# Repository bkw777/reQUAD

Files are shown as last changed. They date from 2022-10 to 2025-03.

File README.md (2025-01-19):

# reQUAD

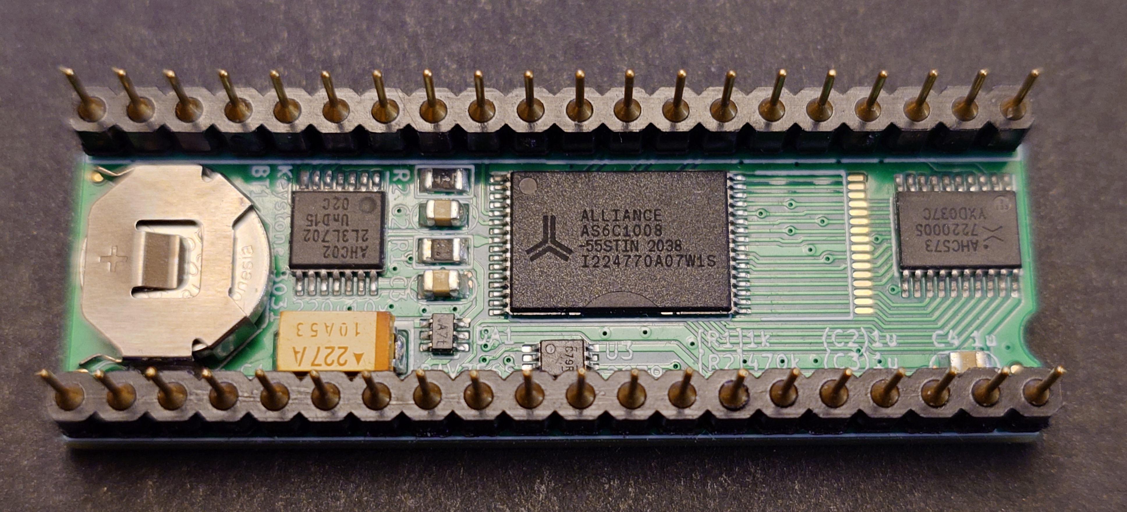
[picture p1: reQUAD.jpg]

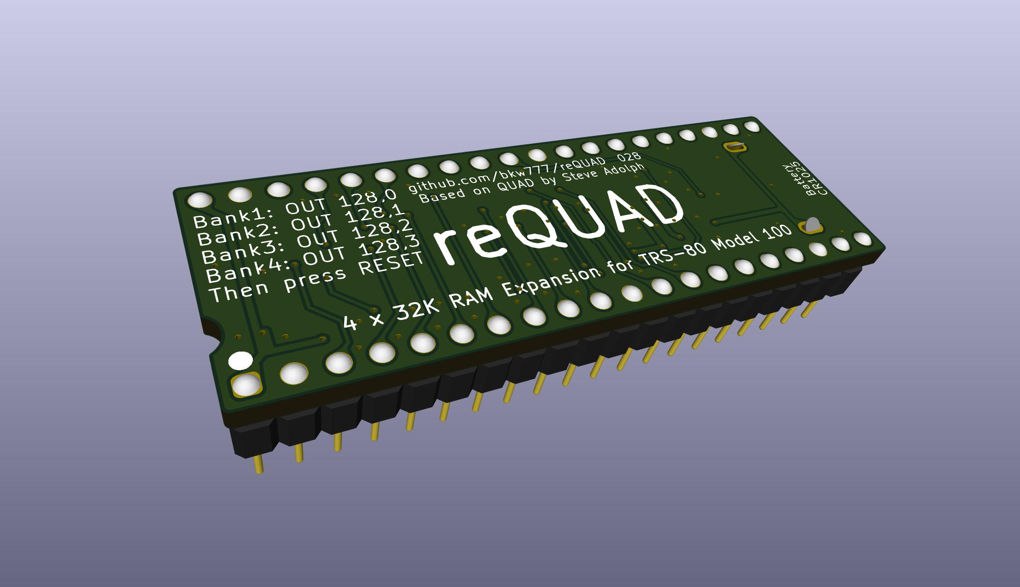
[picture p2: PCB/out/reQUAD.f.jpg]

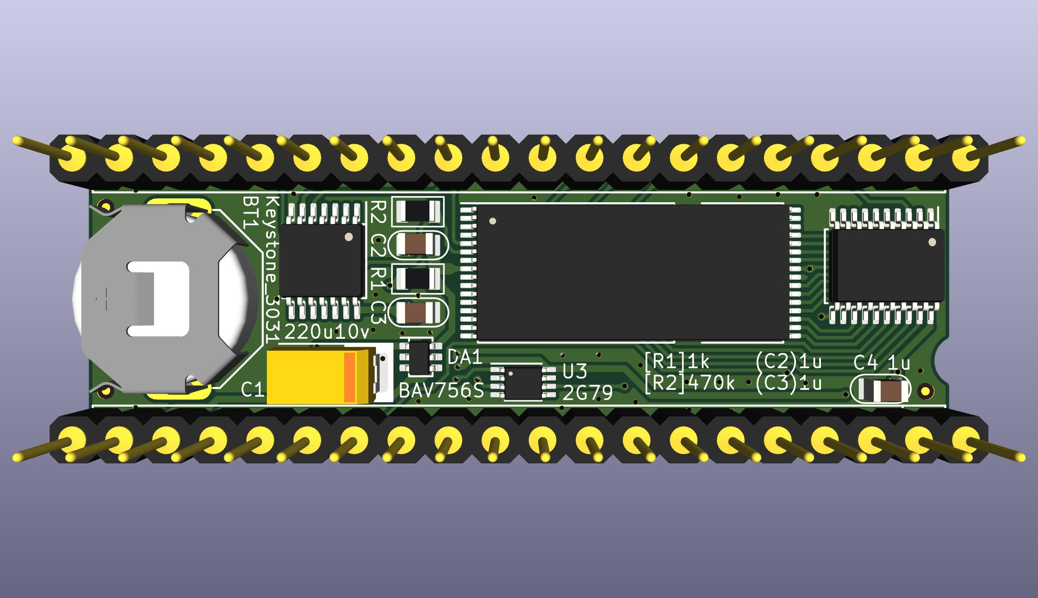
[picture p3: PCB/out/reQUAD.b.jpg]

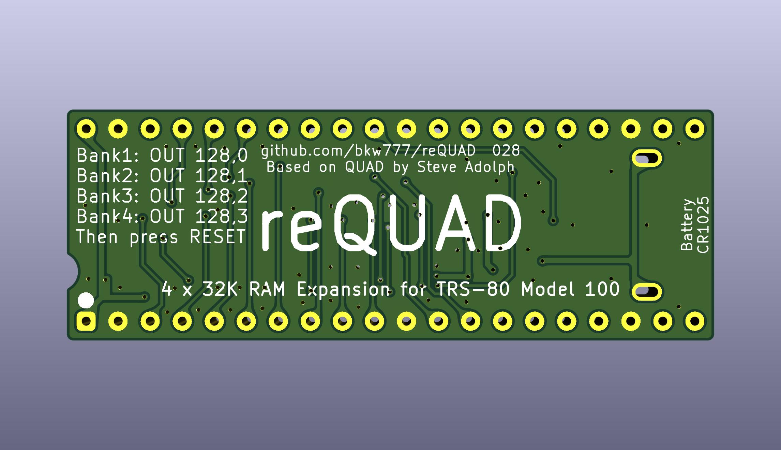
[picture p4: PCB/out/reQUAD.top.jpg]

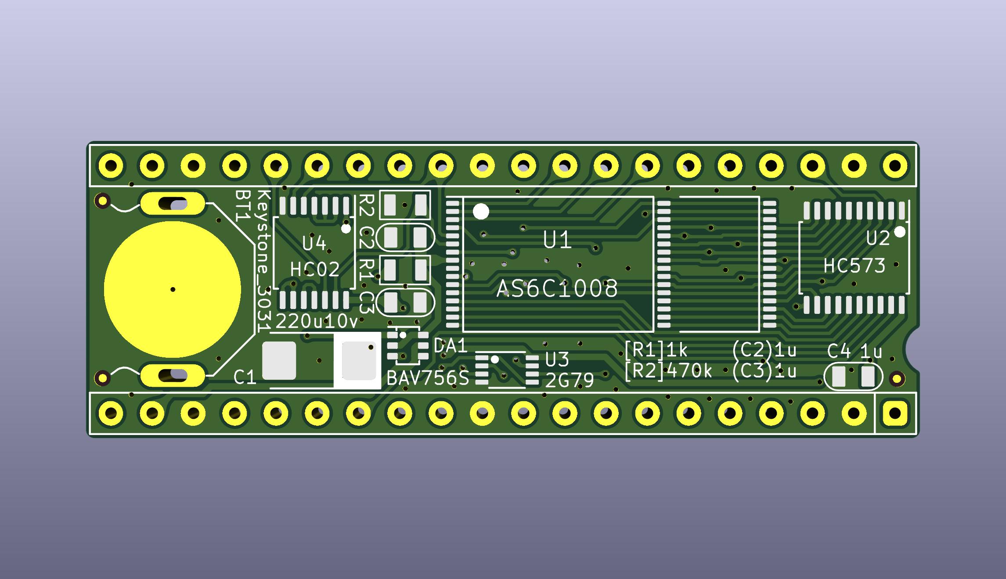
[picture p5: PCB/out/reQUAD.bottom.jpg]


reQUAD.bom.csv

## About
This is a derivative of [QUAD](http://bitchin100.com/wiki/index.php?title=QUAD) by Steve Adolph.

## Differences from the original
Removed the resistor-cap power-on-reset circuit and resettable flip-flop for a simple flip-flop.  
Added battery and battery-change cap.  
Added pulldown on the sram CE2.

## To Build it
PCB [PCBWAY](https://www.pcbway.com/project/shareproject/reQUAD_RAM_Expansion_for_TRS_80_Model_100_8690cd19.html)  
BOM [DigiKey](https://www.digikey.com/short/z47bn0mw)

Build notes,  
The pin 1 mark on DA1, BAV756S, is tiny and faint, but there is one, you just need a lot of magnification and light. The markings look like `.A7t` and the . is at pin 1. The pinout is not symmetric, and so the part must be installed in the correct orientation.

## To Use it

The device disables and replaces the machine's original internal 32k RAM, so copy any files off of the computer before installing the reQUAD. You won't be able to access the internal ram except by removing the reQUAD.

The first time the device is powered up, it will be in a random bank number.

The first thing you should do after install is "blindly" switch to each bank,  
and do a cold-reset in each bank to wipe all banks of any random data.  
(only cold-reset, not power-cycle. If you power-cycle, the reQUAD may switch to a random bank again.)

In BASIC type `OUT 128,3` \[Enter\], then CTRL+BREAK+RESET.  
In BASIC type `OUT 128,2` \[Enter\], then CTRL+BREAK+RESET.  
In BASIC type `OUT 128,1` \[Enter\], then CTRL+BREAK+RESET.  
In BASIC type `OUT 128,0` \[Enter\], then CTRL+BREAK+RESET.  

Now all 4 banks have been wiped clean of any random data, and you are sitting in bank 1.  
From now on, don't do CTRL+BREAK+RESET any more, just RESET (unless you actually want to wipe a bank).  

Now there are 3 main options for using the banks from no on.  
Manual control,  
BANK.BA,  
0QUAD

### Manual Control

To switch banks manually without 0QUAD or BANK.BA:  
In BASIC, type `OUT 128,n`, where n is the desired bank number from 0 to 3,  
then immediately press RESET on the back of the machine.

`OUT 128,0` switches to bank 1  
`OUT 128,1` switches to bank 2  
`OUT 128,2` switches to bank 3  
`OUT 128,3` switches to bank 4  

The cpu has no knowledge that it's entire ram universe has been replaced and all it's current register contents and pointers and such are invalid, so the main rom must be restarted IMMEDIATELY after the OUT command.

So after the OUT command, ignore the screen and press the RESET button on the back of the machine.

Pressing RESET is only needed when switching manually this way instead of using BANK.BA or 0QUAD.  
BANK.BA and 0QUAD both induce a reset themselves.

### BANK.BA
The next-simplest option for controlling the reQUAD is to copy this 4-line BASIC program into each bank,  
and save it with a name matching the current bank it's in.

First, ensure you are in bank 1:  
In BASIC, type `OUT128,0` \[Enter\], then press RESET.

Then in BASIC type-in this program:
```
1 INPUT"Bank(1-4)";X:IFX<1ORX>4THEN 1
2 A#=0:B=VARPTR(A#):POKEB,249
3 POKEB+1,195:POKEB+2,241:POKEB+3,118
4 CALLB,X-1,30481
```

Then `SAVE "BANK1"`

Now you know you are in bank1 because it says BANK1.BA in the main menu,  
and you can BANK1.BA to switch to any other bank.

Repeat for all 4 banks  
run BANK1.BA, answer "2", you are now in a new empty bank2, type-in the program again, `SAVE "BANK2"`  
run BANK2.BA, answer "3", type-in, `SAVE "BANK3"`  
run BANK3.BA, answer "4", type-in, `SAVE "BANK4"`  

### 0QUAD

Install [0QUAD](APP/)

Refer to the docs for the original [QUAD](http://bitchin100.com/wiki/index.php?title=QUAD)

### Example Installing 0QUAD using dl2 and teeny
(this will wipe all data)

QUAD.BA must be copied as a binary via TPDD, it can't be copied in ascii format using ordinary text transfer with TELCOM.  

This example will use dl2 on the pc to bootstrap install TEENY on the 100, and then use TEENY and dl2 to copy QUAD.BA to the 100.
You can use any other TPDD emulator instead of dl2, like LaddieAlpha or a Backpack, and you can use any TPDD client instead of TEENY, like TS-DOS or DSKMGR.

On the pc, install [dl2](https://github.com/bkw777/dl2/)

On the 100, in BASIC: `OUT 128,0`  
Then do a cold reset: CTRL+BREAK+RESET

On the pc:
```
$ cd APP
$ dl -v -b TEENY.100 && dl -v -u
```

On the 100, in BASIC: `RUN "COM:98N1ENN"`  
Press ENTER at the end of the TEENY install to accept the default install location.  
`CLEAR 0,62213`  
Press F8 to exit to the main menu and run TEENY.CO  
Use TEENY to copy QUAD.BA from the pc  
```
> L QUAD  .BA
> Q
```

On the pc: Ctrl+C to exit dl2

On the 100: Run QUAD.BA  
Answer "1" to the "Which bank are you in?" question.  

0QUAD is now installed in bank 1, but is invisible.

Type `0QUAD` \[Enter\] at the main menu (not in BASIC) to run 0QUAD

Now the top-right corner will show "#1" to show that you are currently in bank 1.  
Press F1 to pull up the bank-switch menu, then press F2 to switch to bank 2.

You are now in bank 2 which is a new empty bank.  
0QUAD is not installed in this bank yet.

Install 0QUAD in bank 2 by repeating everything after the OUT command above, including the cold reset.  
Answer "2" at the "Which bank?" question.  
Repeat again for banks 3 and 4.

Once 0QUAD is installed in all banks, you can use it to switch from any bank to any other bank, and you don't need to press the RESET button after each switch when using 0QUAD to switch.

## Thanks
Thanks to Steve Adolph for sharing his original design and allowing this derivative.

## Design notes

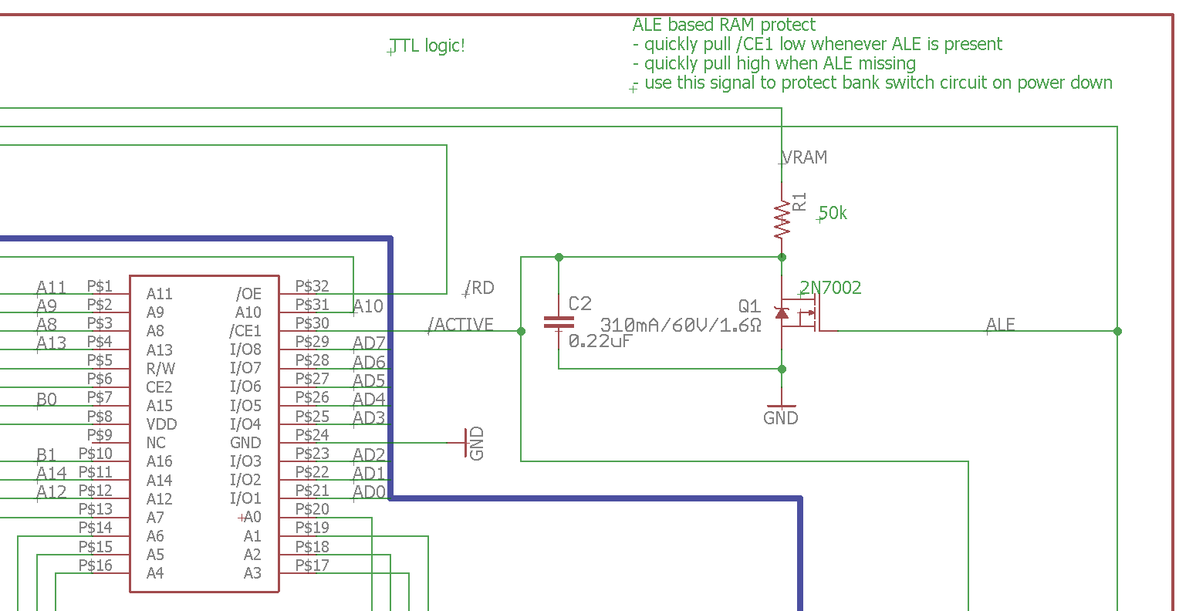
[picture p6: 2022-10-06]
ref/ram_protect_idea.png

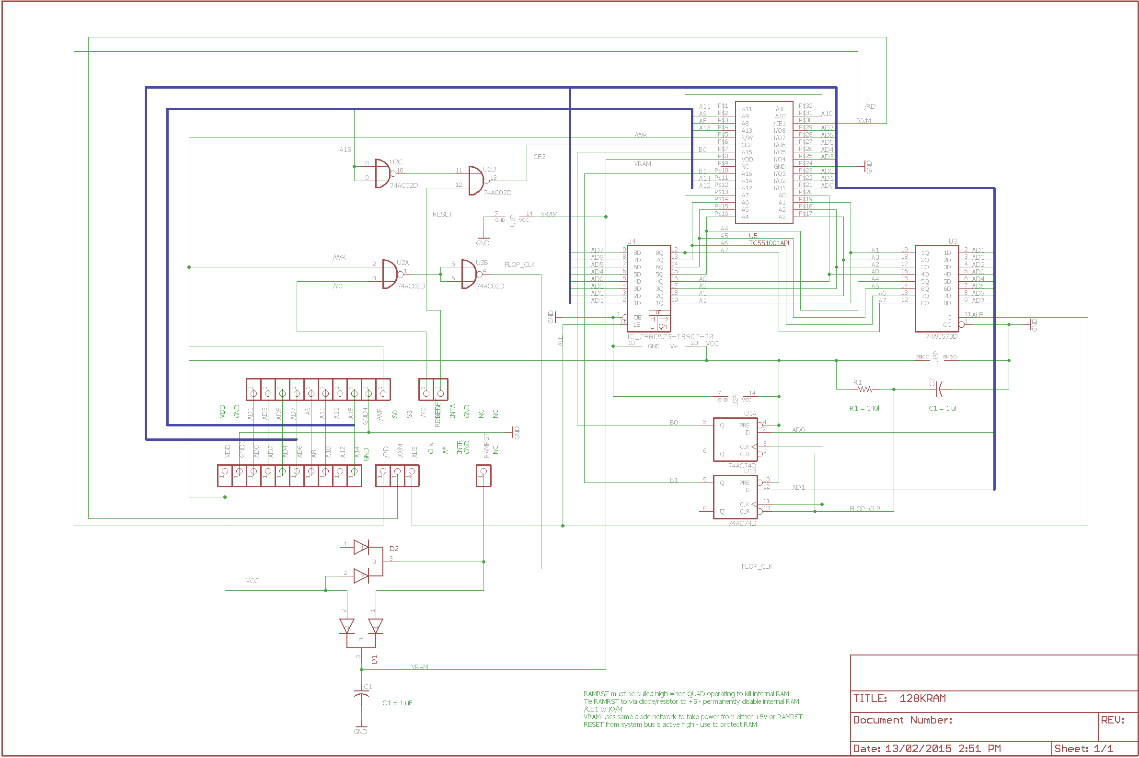
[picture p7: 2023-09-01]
ref/QUAD_v4_schemactic.png

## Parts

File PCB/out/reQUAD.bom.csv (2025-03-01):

Reference | Value | Datasheet | Footprint | Qty | DNP | MPN | Description
BT1 | Keystone_3031 | datasheet/Keystone_3031.pdf | 000_LOCAL:Keystone_3031 | 1 |  | Keystone 3031 | Battery Retainer Coin, 10.0mm 1 Cell PC Pin
C1 | 220u10v | datasheets/TAJ.odf | 000_LOCAL:CP_6032 | 1 |  | TAJC227K010RNJ | CAP TANT 220UF 10% 10V 2312
C2,C3,C4 | 1u | datasheets/CL21B105KAFNNNE.pdf | 000_LOCAL:C_0805 | 3 |  | CL21B105KAFNNNE | CAP CER 1UF 25V X7R 0805
DA1 | BAV756S | datasheets/BAV756S.pdf | 000_LOCAL:SOT-363 | 1 |  | BAV756S,115 | DIODE ARRAY GP 90V 250MA 6TSSOP
J1 | Model_100_System_BUS | datasheets/TRS-80_Model_100_User_Guide.pdf | 000_LOCAL:DIP-40_PCB | 1 |  | 920-0172-01 | CONN HEADER VERT 40P 2.54MM
R1 | 1k | datasheets/RK73.pdf | 000_LOCAL:R_0805 | 1 |  | RK73B2ATTD102J | RES 1K OHM 5% 1/4W 0805
R2 | 470k | datasheets/PYu-RC_Group_51_RoHS_L_12.pdf | 000_LOCAL:R_0805 | 1 |  | RC0805FR-07470KL | RES 470K OHM 1% 1/8W 0805
U1 | AS6C1008 | datasheets/AS6C1008.pdf | 000_LOCAL:TSOP32-dual | 1 |  | AS6C1008-55STIN | IC SRAM 1Mx8 PARALLEL 5V 32STSOP
U2 | HC573 | datasheets/HC573.pdf | 000_LOCAL:TSSOP-20_4.4x6.5mm_P0.65mm | 1 |  | 74HC573PW,118 | IC D-TYPE TRANSP SGL 8:8 20TSSOP
U3 | 2G79 | datasheets/2G79.pdf | 000_LOCAL:VSSOP-8_2.3x2mm_P0.5mm | 1 |  | SN74LVC2G79DCUR | Flip Flop 2 Element D-Type 1 Bit Positive Edge 8-VFSOP (0.091", 2.30mm Width)
U4 | HC02 | datasheets/HC02.pdf | 000_LOCAL:TSSOP-14_4.4x5mm_P0.65mm | 1 |  | 74HC02PW,118 | IC GATE NOR 4CH 2-INP 14TSSOP

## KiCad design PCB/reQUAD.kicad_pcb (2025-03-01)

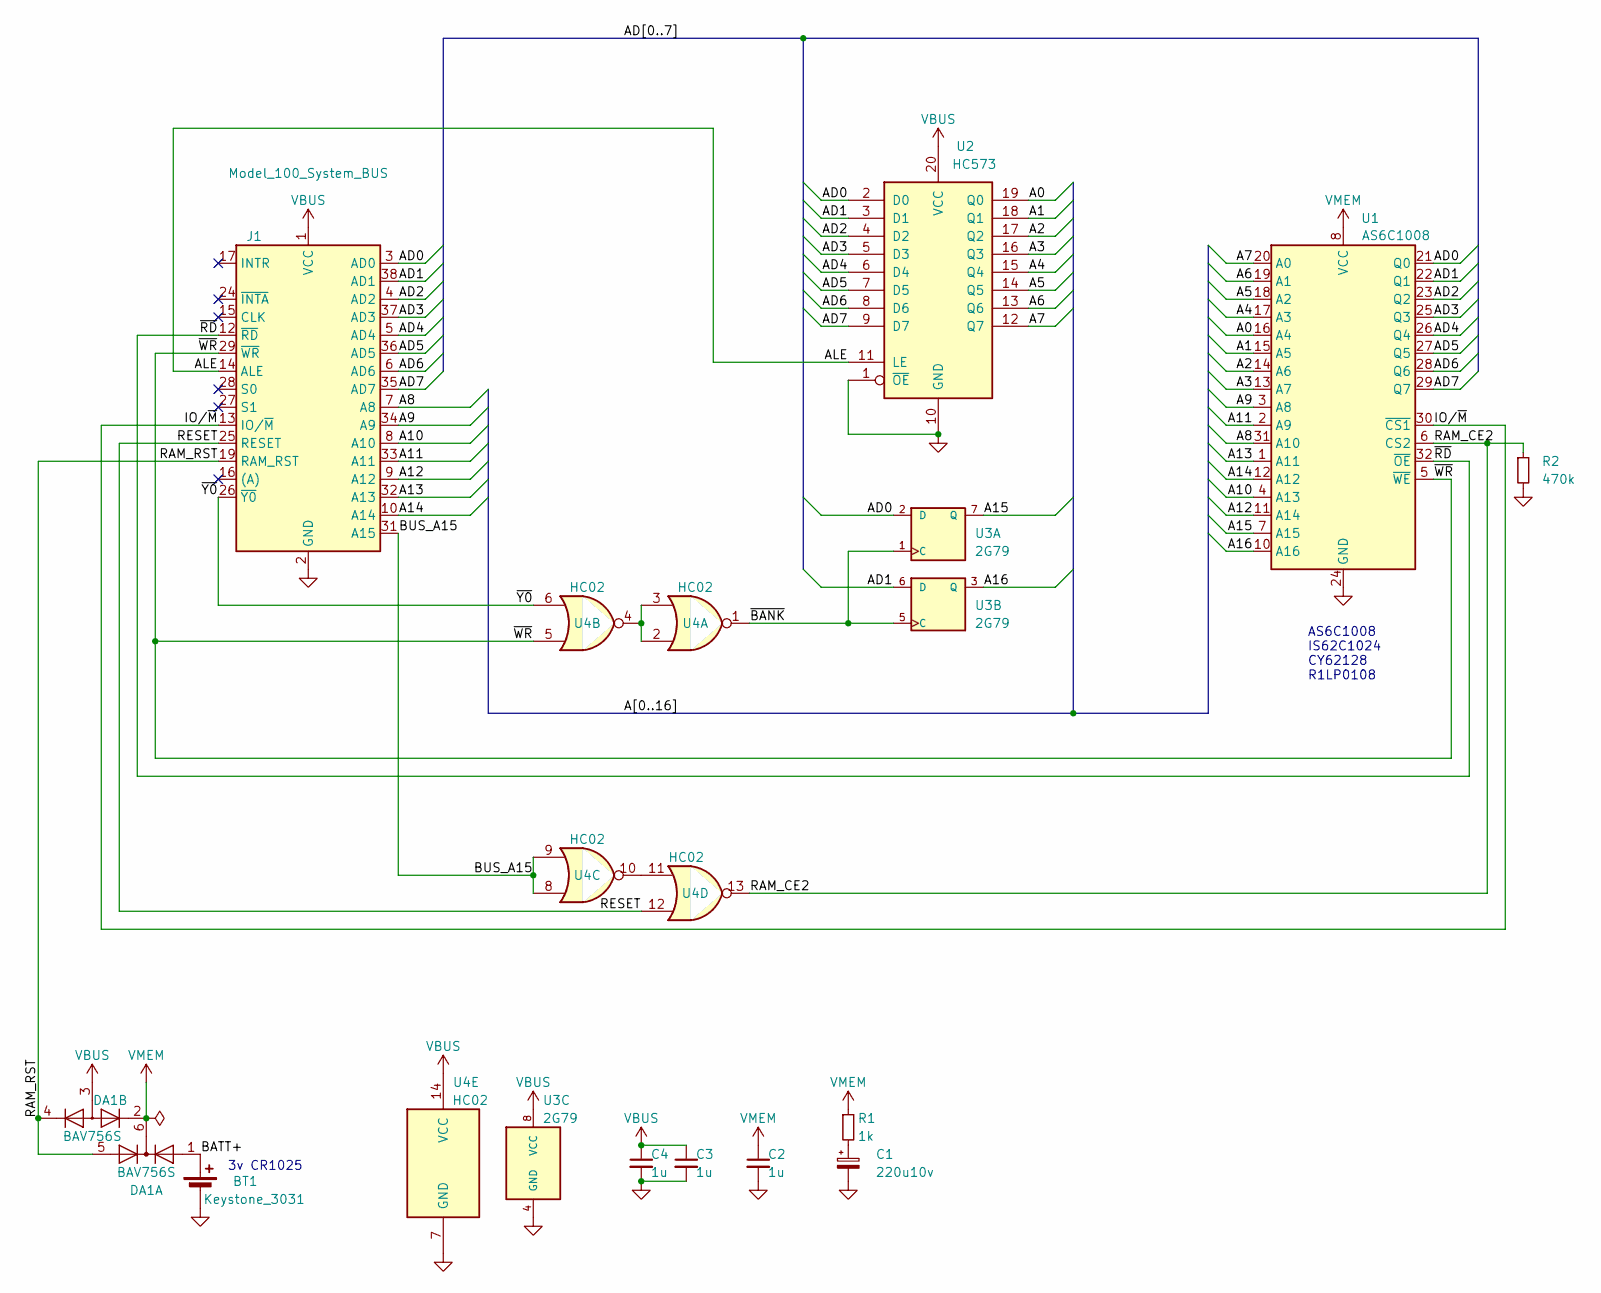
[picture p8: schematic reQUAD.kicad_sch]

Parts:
BT1: Keystone_3031; MPN Keystone 3031
C1: 220u10v; CP_6032; MPN TAJC227K010RNJ
C2, C3, C4: 1u; C_0805; MPN CL21B105KAFNNNE
DA1: BAV756S; SOT-363; MPN BAV756S,115
J1: Model_100_System_BUS; DIP-40_PCB; MPN 920-0172-01
R1: 1k; R_0805; MPN RK73B2ATTD102J
R2: 470k; R_0805; MPN RC0805FR-07470KL
U1: AS6C1008; TSOP32-dual; MPN AS6C1008-55STIN
U2: HC573; TSSOP-20_4.4x6.5mm_P0.65mm; MPN 74HC573PW,118
U3: 2G79; VSSOP-8_2.3x2mm_P0.5mm; MPN SN74LVC2G79DCUR
U4: HC02; TSSOP-14_4.4x5mm_P0.65mm; MPN 74HC02PW,118

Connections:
/A0: U1.16 (A4), U2.19 (Q0)
/A1: U1.15 (A5), U2.18 (Q1)
/A2: U1.14 (A6), U2.17 (Q2)
/A3: U1.13 (A7), U2.16 (Q3)
/A4: U1.17 (A3), U2.15 (Q4)
/A5: U1.18 (A2), U2.14 (Q5)
/A6: U1.19 (A1), U2.13 (Q6)
/A7: U1.20 (A0), U2.12 (Q7)
/A8: J1.7 (A8), U1.31 (A10)
/A9: J1.34 (A9), U1.3 (A8)
/A10: J1.8 (A10), U1.4 (A13)
/A11: J1.33 (A11), U1.2 (A9)
/A12: J1.9 (A12), U1.11 (A14)
/A13: J1.32 (A13), U1.1 (A11)
/A14: J1.10 (A14), U1.12 (A12)
/A15: U1.7 (A15), U3.7 (Q)
/A16: U1.10 (A16), U3.3 (Q)
/AD0: J1.3 (AD0), U1.21 (Q0), U2.2 (D0), U3.2 (D)
/AD1: J1.38 (AD1), U1.22 (Q1), U2.3 (D1), U3.6 (D)
/AD2: J1.4 (AD2), U1.23 (Q2), U2.4 (D2)
/AD3: J1.37 (AD3), U1.25 (Q3), U2.5 (D3)
/AD4: J1.5 (AD4), U1.26 (Q4), U2.6 (D4)
/AD5: J1.36 (AD5), U1.27 (Q5), U2.7 (D5)
/AD6: J1.6 (AD6), U1.28 (Q6), U2.8 (D6)
/AD7: J1.35 (AD7), U1.29 (Q7), U2.9 (D7)
/ALE: J1.14 (ALE), U2.11 (LE)
/BATT+: BT1.1 (+), DA1.1 (A1)
/BUS_A15: J1.31 (A15), U4.8, U4.9
/IO/~M: J1.13 (IO/~M), U1.30 (~CS1)
/RAM_CE2: R2.1, U1.6 (CS2), U4.13
/RAM_RST: DA1.4 (K3), DA1.5 (A4), J1.19 (RAM_RST)
/RESET: J1.25 (RESET), U4.12
/~BANK: U3.1 (C), U3.5 (C), U4.1
/~RD: J1.12 (~RD), U1.32 (~OE)
/~WR: J1.29 (~WR), U1.5 (~WE), U4.5
/~Y0: J1.26 (~Y0), U4.6
GND: BT1.2 (-), C1.2, C2.2, C3.2, C4.2, J1.2 (GND), J1.11 (GND), J1.18 (GND), J1.23 (GND), J1.30 (GND), J1.39 (GND), R2.2, U1.24 (GND), U2.1 (~OE), U2.10 (GND), U3.4 (GND), U4.7 (GND)
unnamed: C1.1, R1.2
unnamed: U4.2, U4.3, U4.4
unnamed: U4.10, U4.11
VBUS: C3.1, C4.1, DA1.3 (CA), J1.1 (VCC), J1.40 (VCC), U2.20 (VCC), U3.8 (VCC), U4.14 (VCC)
VMEM: C2.1, DA1.2 (K2), DA1.6 (CK), R1.1, U1.8 (VCC)

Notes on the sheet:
3v CR1025
AS6C1008 IS62C1024 CY62128 R1LP0108

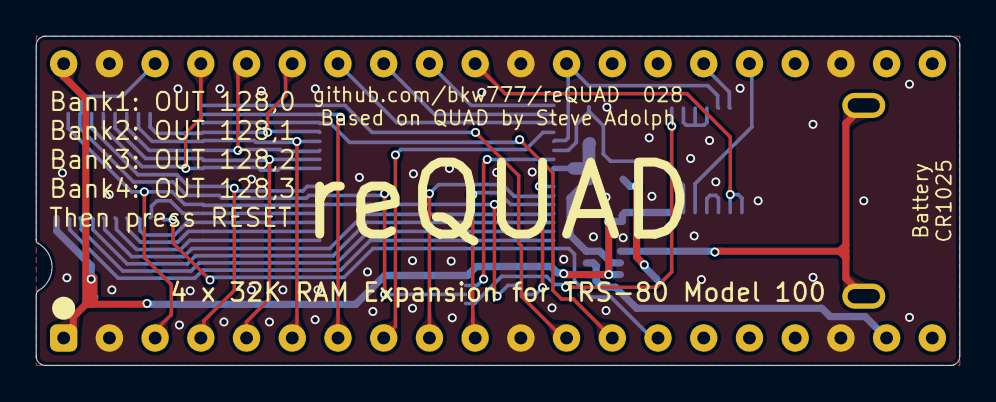
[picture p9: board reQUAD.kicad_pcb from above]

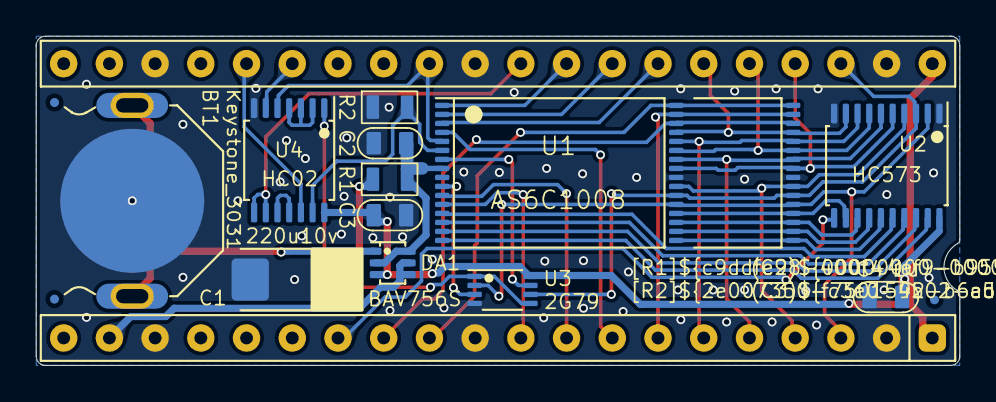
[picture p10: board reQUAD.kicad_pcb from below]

Board: 2 copper layers, 51.3 x 18.3 mm, 16 parts (16 on the bottom side), 42 nets.

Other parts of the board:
F1, F2, F3: Fiducial_0.5_1.0

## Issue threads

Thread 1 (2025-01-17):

v028 Board, Blank Screen after OUT 128,0; Enter; Reset Button

techfixpros, 2025-01-17:
Model 100
FlexROM 102 w/Y2K patched 102 ROM
24k Stock
Recapped and RAM Batt replaced

Built v028 reQUAD, and on initial boot, the total RAM shows 29k, so it was detected and overrode the on-board ram.
Ran OUT 128,0, then enter, then reset button. Screen is now blank, and typing continuously does not make the unit beep.
CTRL+Brk+Reset does not recover unit. Unit will work properly with reQUAD removed.
Removed battery from reQUAD, reinserted and screen is still blank.
Reinserted battery and reQUAD and screen is still blank.

bkw777, 2025-01-18:
As it happens I just built one a week or so ago.

some suggestions:

* cold-reset first thing in any new bank
After switching to any new bank for the first time on a new unit that was just built, or on a unit that has lost all power (both remove the battery and short the big yellow cap), the contents may possibly be random, not valid data and not all clean 00 or FF. So one time per bank, the first time after switching to a new bank that has never been used yet, it's not a bad idea to do a cold-reset: ctrl+break+reset. This wipes all ram in that bank, ensuring it's in a sane state to go from there.

* double-check for shorts on the sram. Soldering the TSOP is tricky and it's easy to have bridges that aren't always obvious visually, like the bridge is behind the pins. So a lot of light and magnification to look real good at the pins.

* double-check for not-really-connected pins on the sram. it's also easy for a pin to look soldered but actually just be resting on top of the pad.

* lake of flux while soldering

You might try just using wick and flux to first soak up the existing solder and re-do the soldering with a lot of flux and more attention to bridges and false not-really-connected, without fully removing the parts.

Really the same applies to all the pins obviously but the TSOP are the smallest and easiest to get an error.

If it really all looks good, get some chipquick or fastchip desoldering alloy and desolder everything and just redo it. You just melt a ball of it on the iron and then run the ball along both rows of pins and after a few swipes back & forth the chip comes loose. Then use wick to clean up the loose chip and it's ready to go on a new board.

* verify the orientation of all ic's
The bav756s is particularly annoying. You have to use a lot of light and magnification to make out the markings ".A7t" and the "." is pin 1.

Here are pics of a working unit for reference of the way the ics should look.

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

After all that, the bad news is, it is actually possible to have a bad ic. I just rescently got a dud 4MB $35 sram for REXCPM. The only way I know the ic was bad and not any of the tricky soldering, is I just have more than one of all parts and I actually desoldered everything and reassembled on a new board, got the same result, replaced just the sram on that same board and it worked. As far as I can remember, that is the only bad ic I got new from digikey or mouser, but it shows that it does happen. Or possibly I killed it in handling. I work on an antistatic mat but I'm not very careful really.

Yours half-working makes me more suspect the 2G79 or possibly any of the other ics since they all play a part in the bank switch, or just general soldering.

The most likely thing is simply the soldering. I've had units not work several times and except for that one bad sram it's always been the soldering, and just redoing it made it work.

bkw777, 2025-01-18:
Wait, how do you have a flexrom 102 in a 100?
Do you actually have one of the late model 100's that doesn't have the non-standard pinout for the main rom?
I've heard of those but never seen one. I figured they were either a myth or very rare.

bkw777, 2025-01-18:
I suppose I could have tested that sram in a tl866 eprom reader. I have the right adapter. Oh well gone now.

techfixpros, 2025-01-18:
> Wait, how do you have a flexrom 102 in a 100? Do you actually have one of the late model 100's that doesn't have the non-standard pinout for the main rom? I've heard of those but never seen one. I figured they were either a myth or very rare.

My original system ROM is a [3256c07-3h1](https://imgur.com/gallery/trs-80-model-100-3256c07-3h1-system-rom-ORf6xtk) <- Is the picture of it.

I will just re-order the parts to populate another reQUAD board (have two more bare). The IC orientation is correct, and I can see the markings on the 756 with my eyeballs, but don't have magnification to see the solder joints in detail.

Also having a problem with the REX Classic, but I think I overheated the voltage regulator (hand soldered the ic's but tried heat gun on the regulator). It is getting 5v in, but only 1.2v out.

techfixpros, 2025-01-18:
Update: I will go ahead and build a new board, and buy a magnifier and chipquick. And probably some pin extensions so I can test it before soldering the pin headers.

After discharging the cap, I can again use the reQUAD, but will not try switching the bank until I have a new one built. Also confirmed with RAMCHK.do that the reQUAD either does use the system memory addressing while the system RAM is disabled and my address circuits are good, or it bypasses it completely. RAMCHK.do with the reQUAD gives 1 beep.

bkw777, 2025-01-18:
Yeah that main rom is standard pinout alright. So flexrom102 is the right one (or any plain real or virtual 27256, but of course you're presumably shooting for the rex classic software main rom function, which needs exactly that board)

I don't know exactly what you're asking about addressing.

I don't know off hand what all besids just the cpu itself generates the ram addresses on the bus, but the quad doesn't do anything but supress the internal ram and respond to the bus as ram.

The internal ram has extra stuff to convert some address bits into 16 different chip-selects for the individual 2k chips on the internal modules, but quad doesn't see any of that, it just sees the full addreess the same way the cpu does.

Normally (no quad) the bus signal ramrst goes low to enable ram, and high to disable it. The 100 holds ramrst high the whole time power is off to disable all ram.

The diodes on quad allow ramrst to power the quads ram while the 100 is off. When the 100 is on the diodes backfeed vcc to ramrst which forces the internal ram to stay disabled at all times, and the quad responds to the bus instead.

bkw777, 2025-02-01:
I think you should have received parts by now. Did you try again yet?

techfixpros, 2025-02-01:
The 220uF tantalum is out of stock until 2/24. Just modified the order to ship everything else and ship it when it is back in stock. When I receive the partial shipment, I will recover the one from the bad board.

bkw777, 2025-02-01:
You can use almost anything or even leave it off. It's only for changing the battery without losing data. As little as 47uF will still give you several seconds or even tens of seconds. Just don't go below 10v rating. It should be no problem to recover from the old board with either hot air or with chipquick.

My own unit gave me some crashes initially which just turned out to be the main connection of the dip-40 pins in the socket. Removed and reinserted a couple times and it started working right.

Also I noticed mine seems to always power-up into bank 2, not 1. So during initial setup it is important not to skip the "blind switch to bank 1, and don't power-cycle after that" first step before loading in bank.ba or menu.ba

techfixpros, 2025-02-08:
Just soldered up another one without the big cap and battery slot. On first power on the computer hummed and the display was blank. Second power on the screen worked properly, but there were artifacts on the screen until I powered down, removed the requad, and reset the memory. I will order the parts for one more try, and also compare the 026 the 028 and see if my last attempt will be on that revision instead.

Feel free to close this as it has to be my soldering, although this time I have a nice lighted magnifying glass to solder under and fixed all of the bridges. I may have toasted some components this time since I also got a hot air station and tried that at 370C - 500C (the solder paste would not melt). I used a lake of flux and it wouldn't melt, so I went back with the iron.

bkw777, 2025-02-09:
It sounds like I should really try to develop some kind of diagnostic procedures to test all the connections to find shorts. Without that, it's "solder it all up and hope it works" and if it doesn't work, you have no idea which of 100 different things it could be.

I am curious. Would you be willing to mail me your non-working rex and requad for working ones? Probably what I'll do is repair yours and tell you what was wrong, or if yours are somehow unsalvageable I'll just give you ones I already have. It's no problem. I have parts for many and have built many because every time I change anything I build at least one to make sure it's actually good.

I want to see what actually is wrong with yours, because you are using the same pcb versions and components as I am, and your 100 seems to be working on it's own.
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
techfixpros, 2025-02-11:
You were correct that the FlexROM needing to be reflashed being a  bad assumption. Ctrl+Break+Reset does in fact recover the computer after scrambling it with the REX. Doing a LIST in basic after scrambling it shows random actual program data before resetting it, so indeed the memory is getting filled with something.

Thanks for your offer in looking into what I did wrong, or whatever is wrong with these boards. Emailed my address.

I have a Pinecil v1, and use Essmetuin no-clean flux, Wonderway 63/37 solder paste, and kester rosin-core solder.

The first two boards (quad and rex) I ran a bead of paste, set the part, and ran a bead of flux over it. Then drag-soldered them. Used MG 424-NS #2 wick to clean excess that wouldn't come off on a dry tip, and dragged again to flow some more on without bridging. Cleaned with 90% IPA and a soft tooth brush.

The second boards I tacked opposite corners, ran a bead of flux, then used the kester spool-solder to hit each un-tinned leg and pad. Used the wick to remove excess again, and touched up whatever I used the wick on. This time they were cleaned with MG 4140A.
I do not have nearly as sophisticated setup as you with vices

bkw777, 2025-05-12:
I finally looked ove rthese boards and found a few simple solder shorts on one board, and did not actually find anything wrong with the other, although I did reflow some pins just to make them look better, and in the end both boards are fully working. So I'm closing this issue since it doesn't appear there is a problem with the schematic or pcb art.

The REX's were the same. One had a bad Xilinx chip internally shorting vcc to gnd, thus the burned out ldo, and the other had simple solder shorts on a couple flash pins, thus the data corruption. Bot hrexes fully working now.

Closed 2025-05-12.

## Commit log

2022-08-22 increase few minor clearances
    [reQUAD.kicad_pcb]
2022-08-24 Try Steve's new idea: Pull (A)* low instead of pulling RAMRST high
    [reQUAD.kicad_pcb, reQUAD.kicad_sch]
2022-08-29 pcb routing vcc vmem A0-A3
    [reQUAD.kicad_pcb, reQUAD.kicad_sch]
2022-08-29 vias on vcc & vmem
    [reQUAD.kicad_pcb]
2022-08-29 vcc routing
    [reQUAD.kicad_pcb]
2022-08-30 renders and minor pcb layout adjustments
    [reQUAD.kicad_pcb, reQUAD.kicad_sch]
2022-08-30 dip pins footprint & board outline
    [reQUAD.kicad_pcb]
2022-08-30 outline, fiducials
    [reQUAD.kicad_pcb]
2022-09-07 smaller file size 3d model for pins
    [reQUAD.kicad_pcb]
2022-10-06 only need the flipflops on vmem?
    [reQUAD.kicad_pcb, reQUAD.kicad_sch]
2023-04-14 add vcc cap
    [reQUAD.kicad_pcb, reQUAD.kicad_sch]
2023-09-01 standard pins, add 47u on vmem
    [reQUAD.BOM.csv, reQUAD.kicad_pcb, reQUAD.kicad_sch]
2023-09-04 renders & readme
    [reQUAD.kicad_pcb]
2023-09-24 volotile latches, battery
    [reQUAD.kicad_pcb, reQUAD.kicad_sch, reQUAD_20.kicad_pcb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]
2023-09-26 tiny pcb layout nudges
    [reQUAD_20.kicad_pcb, reQUAD_20.kicad_sch]
2023-09-26 make v020 main even though not tested yet
    [reQUAD.BOM.csv, reQUAD.kicad_pcb, reQUAD.kicad_sch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]
2023-10-02 add series resistor on tantalum
    [reQUAD.kicad_pcb, reQUAD.kicad_sch, reQUAD_018.kicad_pcb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]
2023-10-03 routing R2
    [reQUAD.kicad_pcb]
2023-10-03 R1 more common value
    [reQUAD.BOM.csv, reQUAD.kicad_pcb, reQUAD.kicad_sch]
2023-10-18 add fiducials
    [reQUAD.kicad_pcb, reQUAD.kicad_sch]
2023-11-05 batt footprint, vbus & gnd routing near pin 1
    [reQUAD.kicad_pcb]
2023-11-22 battery footprint
    [reQUAD.kicad_pcb, reQUAD.kicad_sch]
2023-12-18 sch tidy
    [reQUAD.kicad_sch]
2024-03-07 kicad 8
    [reQUAD.kicad_pcb, reQUAD.kicad_sch]
2024-11-21 improve hand-solderability of TSSOP parts
    [reQUAD.bom.csv, reQUAD.kicad_pcb, reQUAD.kicad_sch]
2024-11-21 TSSOP footprints, silkscreen, MPN & bom export from sch, centroid export
    [reQUAD.BOM.csv, reQUAD.bom.csv, reQUAD.kicad_pcb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]
2024-11-21 TSOP32 footprint, arrange R1 R2 C2 C3 for easier hand soldering
    [reQUAD.kicad_pcb]
2024-11-23 028 - tsop32 footprint
    [reQUAD.kicad_pcb, reQUAD.kicad_sch]
2025-03-01 correct MPN for VSSOP-8 package 2G79
    [reQUAD.bom.csv, reQUAD.kicad_pcb, reQUAD.kicad_sch]
